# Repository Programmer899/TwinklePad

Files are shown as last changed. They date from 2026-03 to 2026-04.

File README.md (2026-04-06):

# Twinklepad

This is a small multi task keyboard with 3 custom modes, featuring a TRRS port for double connection, 2 encoders using GPIO and a display for displaying different contents.

Note that the parts that is not a part of the HackPad (https://blueprint.hackclub.com/home) guide will be bought or funded yourself.

---

## Features
1 pcs of 3 step toggle for switching mode
4x4 matrix of key switches
2 pcs of encoders for example slider values such as volume
1 ssd1306 128x32 display for displaying different types of content
1 TRRS port for dual connected modules (could be used for a split keyboard as an example)

---

## Modes

The Twinklepad has 3 modes by default
- Music mode (to the left) - when you press a key it plays a note
- Normal mode (in the middle) - when you press a key it forwards that to the pc as a keycode input
- Calc mode (on the right) - For future calculator mode, able to calculate differents formulas

The current mode for my trinklepad is shown on the display by default.
---

My firmware is written in c from the ground up and has some different features such as:
- Matrix scanning for key inputs
- Encoder control (default: only left is connected to "pitch")
- Display - only capable of displaying mode by default

---

## Hardware

- Raspberry Pi Pico 2 W
- 4x4 MX-style switches  
- 2 pcs Rotary encoders (with push buttons)
- SK6812-MINI-E LEDs 
- SSD1306 128x32 OLED
- Piezo buzzer 4.5 khz
- 3-position mode switch (ON-OFF-ON)

---

## Preview

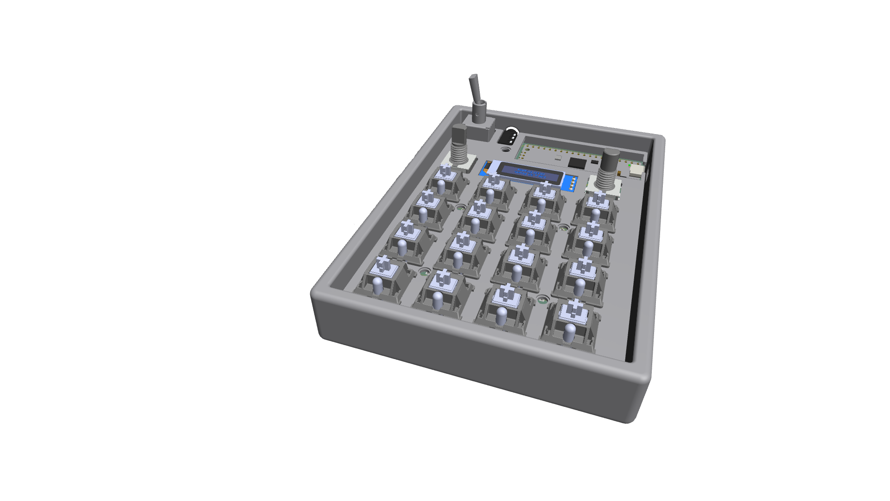
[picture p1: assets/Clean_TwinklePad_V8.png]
Twinklepad Preview


---

## Getting Started

Clean software:
1. Build with Pico SDK (CMake + Ninja)
2. Flash the `.uf2` file to the Pico
3. Connect via USB and start using HackPad

Use mine?
Just flash the .uf2 file in the fully assembled/production folder.

---

## Notes

This is one of my first times doing something like this.

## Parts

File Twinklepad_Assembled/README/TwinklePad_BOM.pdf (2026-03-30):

# Twinkle Pad BOM

MX Cherry switches for rgb: Cherry MX Red RGB (https://www.keychron.com/products/cherry-switch-set?variant=39317191196761) 16 pcs (4x4)

Raspberry Pico 2 W: Raspberry-pi-pico-2w (https://www.electrokit.com/raspberry-pi-pico-2w) 1 pcs

Buzzer: piezo-transducer-4.5khz (https://www.electrokit.com/piezo-transducer-4.5khz) 1 pcs

Sparkfun TRRS: PRT-12639_SparkFun (https://componentsearchengine.com/part-view/PRT-12639/SparkFun) 1 pcs

RGB SK6812MINI-E: SK6812MINI-E_REV02 (https://cdn-shop.adafruit.com/product-files/4960/4960_SK6812MINI-E_REV02_EN.pdf) 16 pcs

Rotary Encoders: tech.alpsalpine.com - ec11e (https://tech.alpsalpine.com/e/products/category/encorders/sub/01/series/ec11e/) 2 pcs

Display SSD1306 0.91: www.az-delivery.de - SSD1306 0.91 i2c-oled-display (https://www.az-delivery.de/en/products/0-91-zoll-i2c-oled-display) 1 pcs

3 Step switch 7205P3Y9CQE: www.mouser.se - 7205P3Y9CQE (https://www.mouser.se/ProductDetail/CK/7205P3Y9CQE?qs=ZI7IIxmAbBLtiAhiSZhUWA%3D%3D) 1 pcs

### Guides:

Buzzer Guide: pico-2w-kit/en/latest/pyproject/py_pa_buz (https://docs.sunfounder.com/projects/pico-2w-kit/en/latest/pyproject/py_pa_buz.html)

Twinkle Pad BOM | 1

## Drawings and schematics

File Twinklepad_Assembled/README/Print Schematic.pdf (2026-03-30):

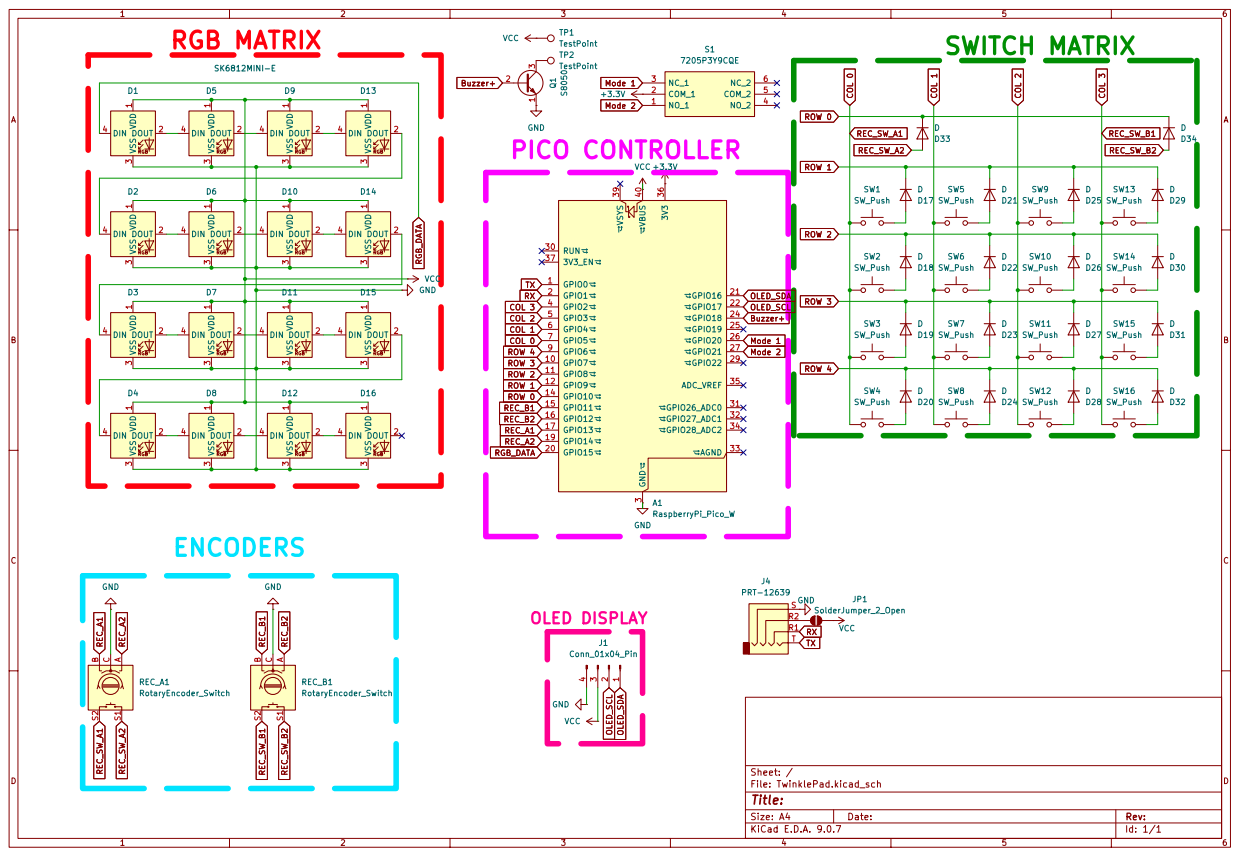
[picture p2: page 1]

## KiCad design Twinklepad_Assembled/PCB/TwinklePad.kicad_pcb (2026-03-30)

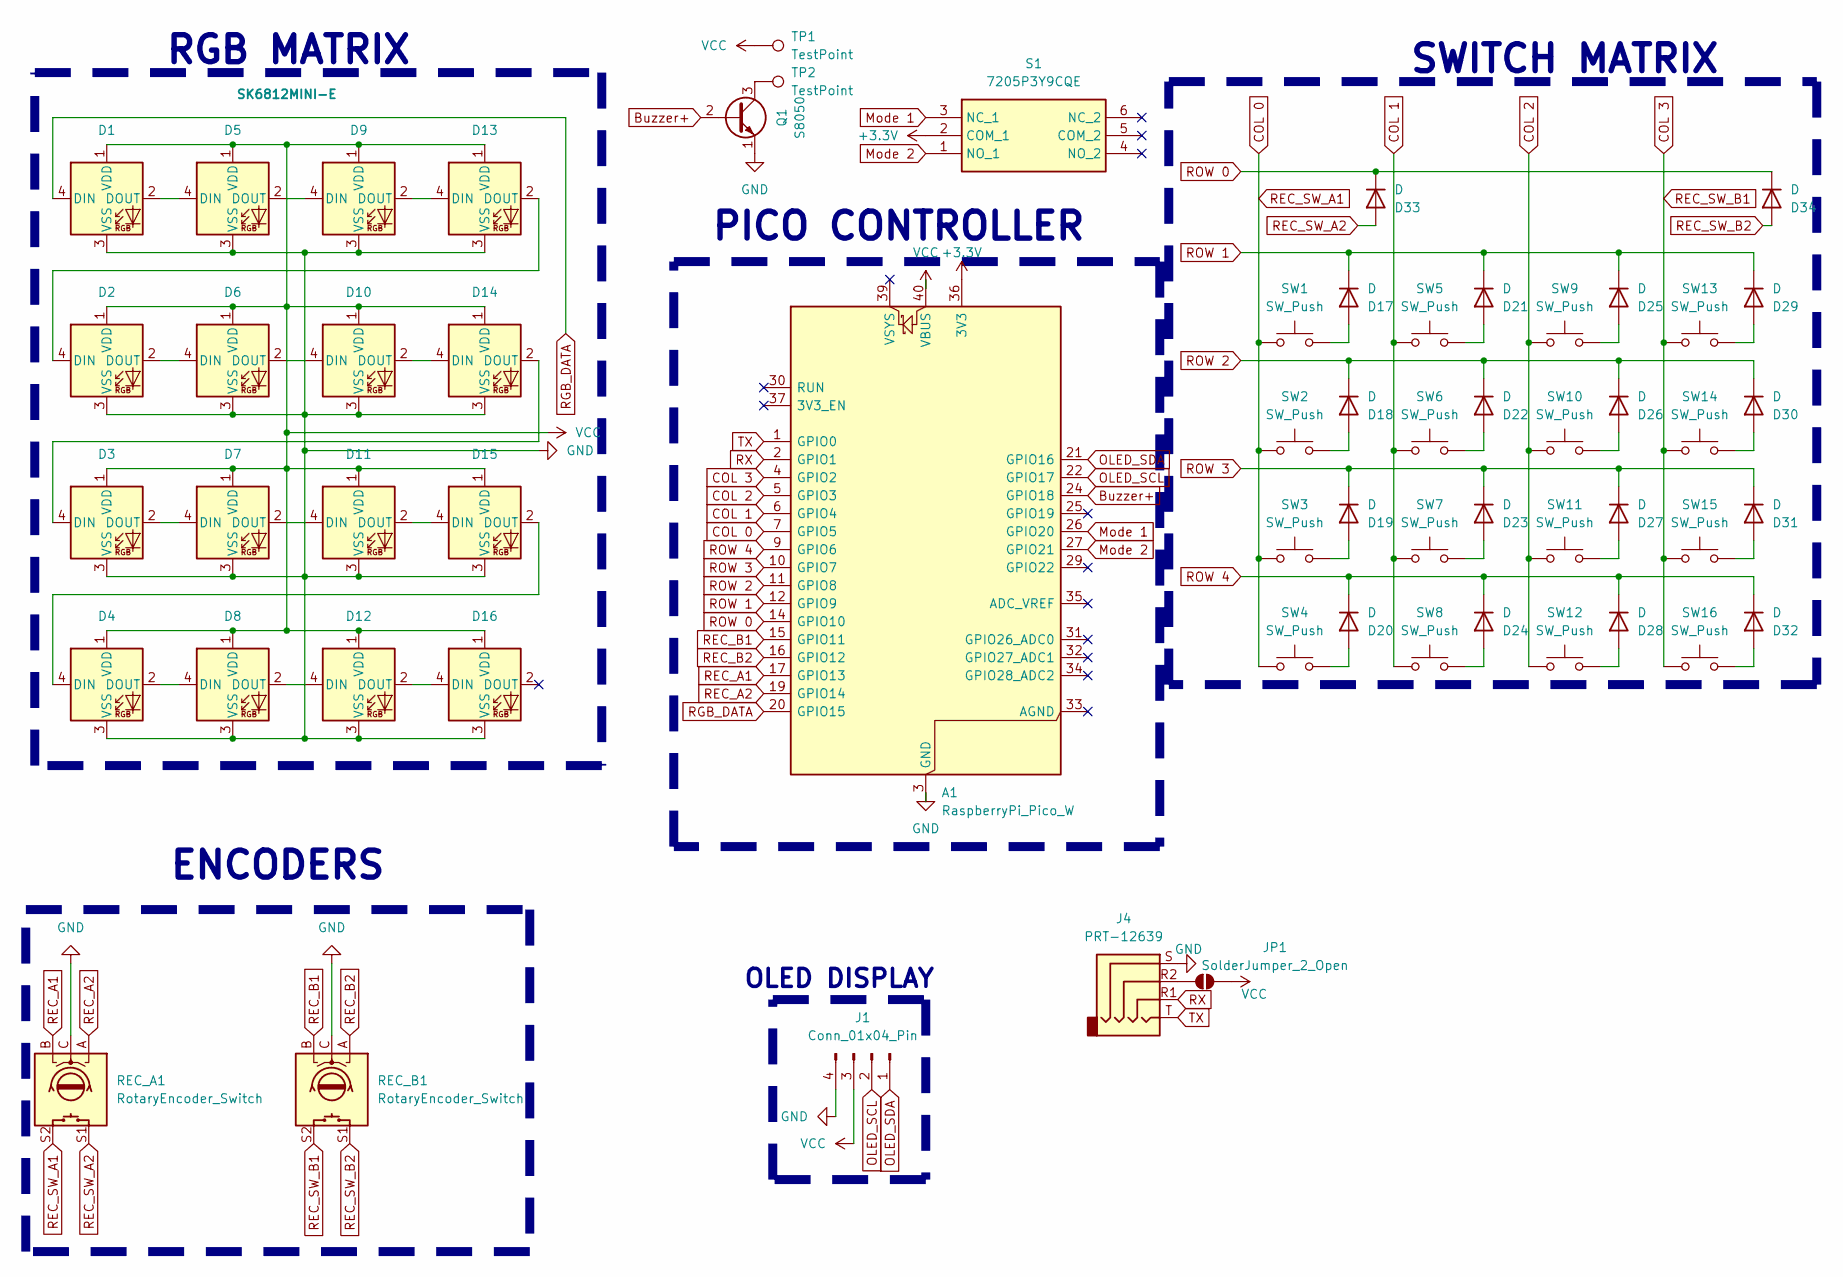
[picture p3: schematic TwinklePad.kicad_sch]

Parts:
A1: RaspberryPi_Pico_W; RaspberryPi_Pico_Common_Unspecified
D1, D2, D3, D4, D5, D6, D7, D8, D9, D10, D11, D12, D13, D14, D15, D16: SK6812MINI-E; SK6812MINI-E_fixed
D17, D18, D19, D20, D21, D22, D23, D24, D25, D26, D27, D28, D29, D30, D31, D32, D33, D34: D; D_DO-35_SOD27_P7.62mm_Horizontal
J1: Conn_01x04_Pin; SSD1306-0.91-OLED-4pin-128x32
J4: PRT-12639; PRT12639; Manufacturer_Part_Number PRT-12639; Mouser Part Number 474-PRT-12639
JP1: SolderJumper_2_Open; SolderJumper-2_P1.3mm_Open_RoundedPad1.0x1.5mm
Q1: S8050; TO-92_Inline_Horizontal1
REC_A1: RotaryEncoder_Switch; RotaryEncoder_Alps_EC11E-Switch_Vertical_H20mm
REC_B1: RotaryEncoder_Switch; RotaryEncoder_Alps_EC11E-Switch_Vertical_H20mm
S1: 7205P3Y9CQE; Manufacturer_Part_Number 7205P3Y9CQE; Mouser Part Number 611-7205P3Y9CQE
SW1, SW2, SW3, SW4, SW5, SW6, SW7, SW8, SW9, SW10, SW11, SW12, SW13, SW14, SW15, SW16: SW_Push; MX-Hotswap-1U
TP1, TP2: TestPoint; TestPoint_Plated_Hole_D2.0mm

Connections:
+3.3V: A1.36 (3V3), S1.2 (COM_1)
Buzzer+: A1.24 (GPIO18), Q1.2 (B)
COL 0: A1.7 (GPIO5), REC_A1.S2, SW1.1, SW2.1, SW3.1, SW4.1
COL 1: A1.6 (GPIO4), SW5.1, SW6.1, SW7.1, SW8.1
COL 2: A1.5 (GPIO3), SW9.1, SW10.1, SW11.1, SW12.1
COL 3: A1.4 (GPIO2), REC_B1.S2, SW13.1, SW14.1, SW15.1, SW16.1
GND: A1.3 (GND), A1.8 (GND), A1.13 (GND), A1.18 (GND), A1.23 (GND), A1.28 (GND), A1.38 (GND), D1.3 (VSS), D2.3 (VSS), D3.3 (VSS), D4.3 (VSS), D5.3 (VSS), D6.3 (VSS), D7.3 (VSS), D8.3 (VSS), D9.3 (VSS), D10.3 (VSS), D11.3 (VSS), D12.3 (VSS), D13.3 (VSS), D14.3 (VSS), D15.3 (VSS), D16.3 (VSS), J1.4, J4.S, Q1.1 (E), REC_A1.C, REC_B1.C
Mode 1: A1.26 (GPIO20), S1.3 (NC_1)
Mode 2: A1.27 (GPIO21), S1.1 (NO_1)
unnamed: D1.2 (DOUT), D5.4 (DIN)
unnamed: D2.2 (DOUT), D6.4 (DIN)
unnamed: D3.2 (DOUT), D7.4 (DIN)
unnamed: D4.2 (DOUT), D8.4 (DIN)
unnamed: D5.2 (DOUT), D9.4 (DIN)
unnamed: D6.2 (DOUT), D10.4 (DIN)
unnamed: D10.2 (DOUT), D14.4 (DIN)
unnamed: D7.2 (DOUT), D11.4 (DIN)
unnamed: D11.2 (DOUT), D15.4 (DIN)
unnamed: D8.2 (DOUT), D12.4 (DIN)
unnamed: D12.2 (DOUT), D16.4 (DIN)
unnamed: D9.2 (DOUT), D13.4 (DIN)
unnamed: D2.4 (DIN), D13.2 (DOUT)
unnamed: D3.4 (DIN), D14.2 (DOUT)
unnamed: D4.4 (DIN), D15.2 (DOUT)
unnamed: D17.2 (A), SW1.2
unnamed: D18.2 (A), SW2.2
unnamed: D19.2 (A), SW3.2
unnamed: D20.2 (A), SW4.2
unnamed: D21.2 (A), SW5.2
unnamed: D22.2 (A), SW6.2
unnamed: D23.2 (A), SW7.2
unnamed: D24.2 (A), SW8.2
unnamed: D25.2 (A), SW9.2
unnamed: D26.2 (A), SW10.2
unnamed: D27.2 (A), SW11.2
unnamed: D28.2 (A), SW12.2
unnamed: D29.2 (A), SW13.2
unnamed: D30.2 (A), SW14.2
unnamed: D31.2 (A), SW15.2
unnamed: D32.2 (A), SW16.2
unnamed: J4.R2, JP1.1 (A)
unnamed 41: Q1.3 (C), TP2.1; also elsewhere on the board
OLED_SCL: A1.22 (GPIO17), J1.2
OLED_SDA: A1.21 (GPIO16), J1.1
REC_A1: A1.17 (GPIO13), REC_A1.B
REC_A2: A1.19 (GPIO14), REC_A1.A
REC_B1: A1.15 (GPIO11), REC_B1.B
REC_B2: A1.16 (GPIO12), REC_B1.A
REC_SW_A2: D33.2 (A), REC_A1.S1
REC_SW_B2: D34.2 (A), REC_B1.S1
RGB_DATA: A1.20 (GPIO15), D1.4 (DIN)
ROW 0: A1.14 (GPIO10), D33.1 (K), D34.1 (K)
ROW 1: A1.12 (GPIO9), D17.1 (K), D21.1 (K), D25.1 (K), D29.1 (K)
ROW 2: A1.11 (GPIO8), D18.1 (K), D22.1 (K), D26.1 (K), D30.1 (K)
ROW 3: A1.10 (GPIO7), D19.1 (K), D23.1 (K), D27.1 (K), D31.1 (K)
ROW 4: A1.9 (GPIO6), D20.1 (K), D24.1 (K), D28.1 (K), D32.1 (K)
RX: A1.2 (GPIO1), J4.R1
TX: A1.1 (GPIO0), J4.T
VCC: A1.40 (VBUS), D1.1 (VDD), D2.1 (VDD), D3.1 (VDD), D4.1 (VDD), D5.1 (VDD), D6.1 (VDD), D7.1 (VDD), D8.1 (VDD), D9.1 (VDD), D10.1 (VDD), D11.1 (VDD), D12.1 (VDD), D13.1 (VDD), D14.1 (VDD), D15.1 (VDD), D16.1 (VDD), J1.3, JP1.2 (B), TP1.1; also elsewhere on the board

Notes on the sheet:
RGB MATRIX
SWITCH MATRIX
PICO CONTROLLER
ENCODERS
OLED DISPLAY

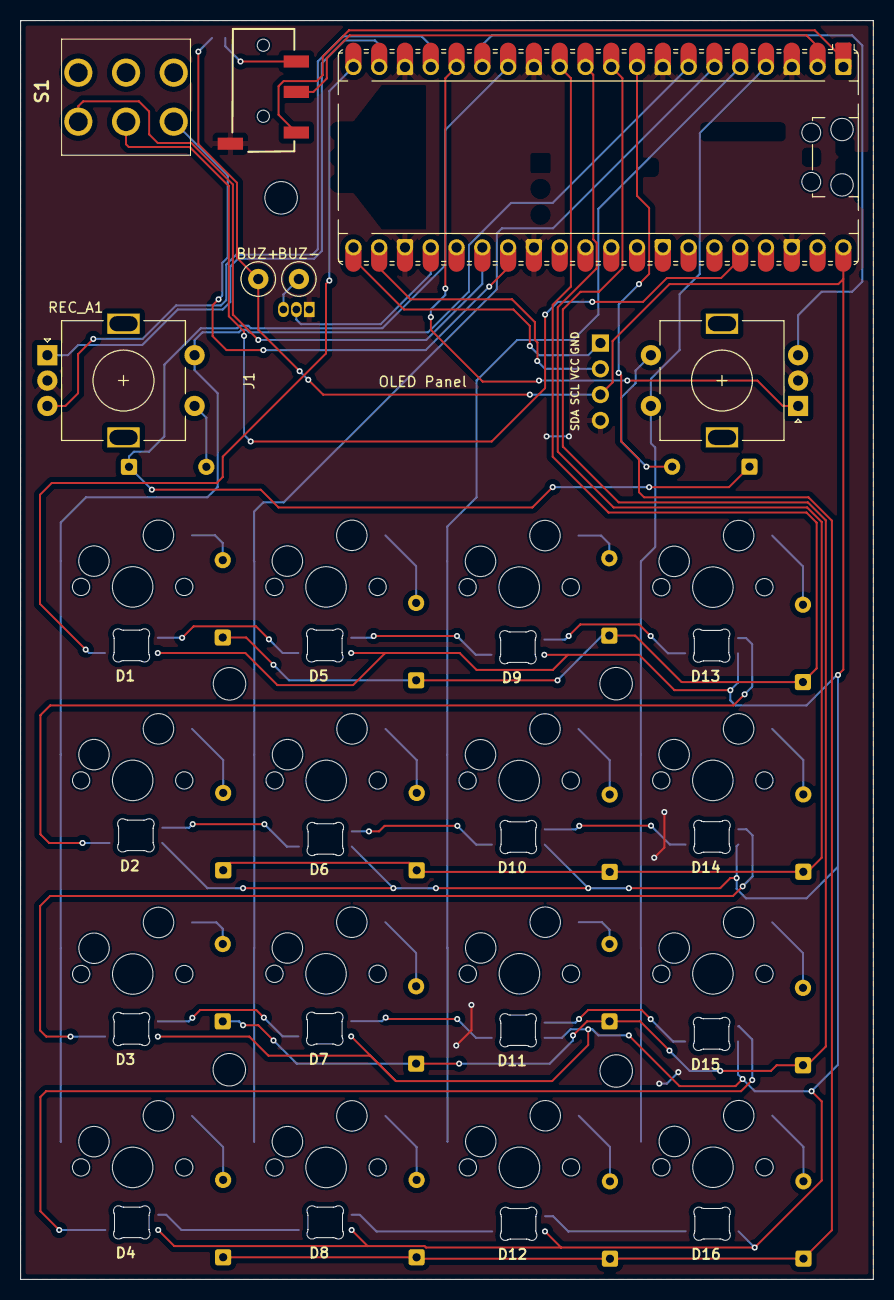
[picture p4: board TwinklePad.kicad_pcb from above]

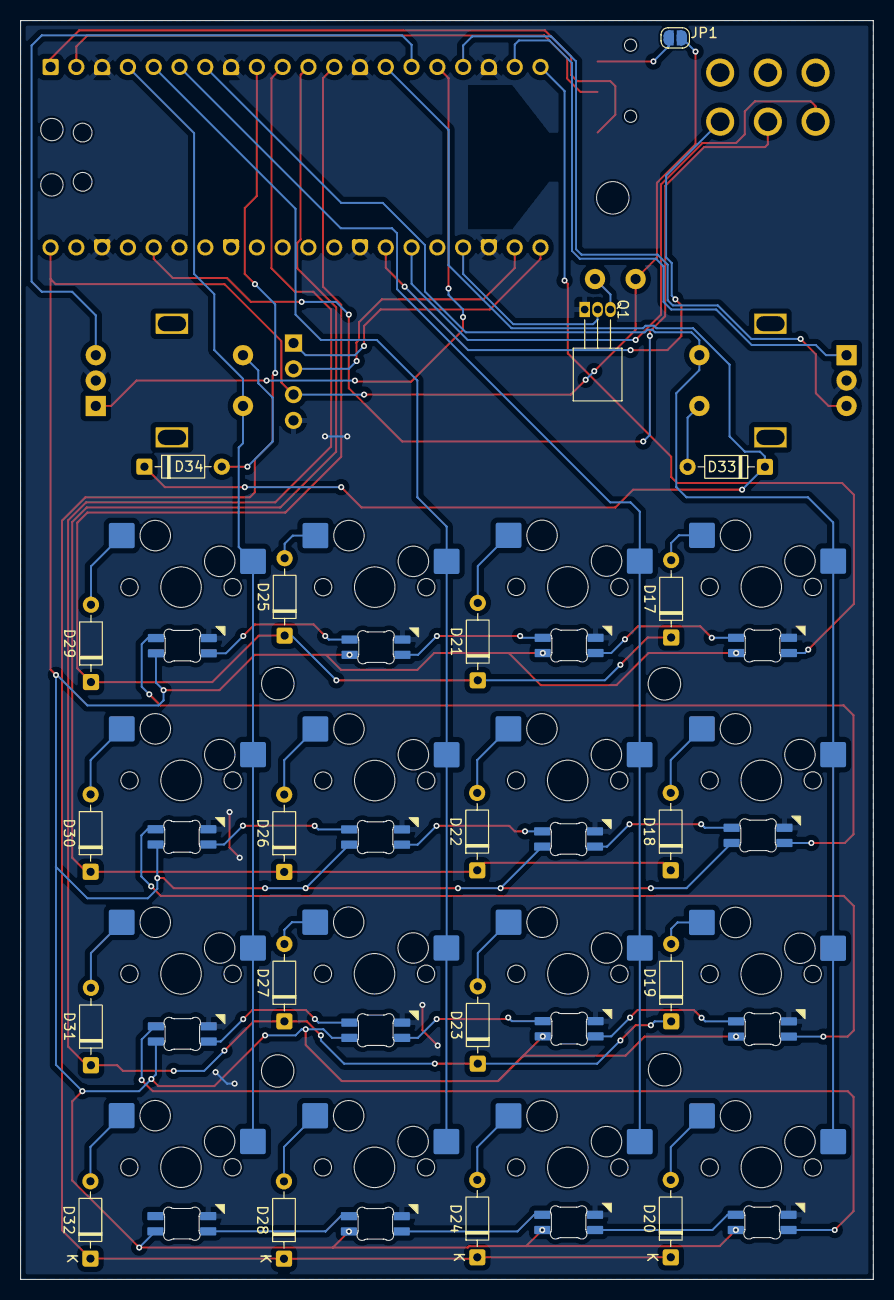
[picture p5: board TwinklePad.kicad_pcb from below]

Board: 2 copper layers, 84.0 x 124.0 mm, 60 parts (36 on the bottom side), 59 nets.

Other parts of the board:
BUZ+: TestPoint; TestPoint_Plated_Hole_D2.0mm
BUZ-: TestPoint; TestPoint_Plated_Hole_D2.0mm

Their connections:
unnamed 41: BUZ-.1; also elsewhere on the board
VCC: BUZ+.1; also elsewhere on the board

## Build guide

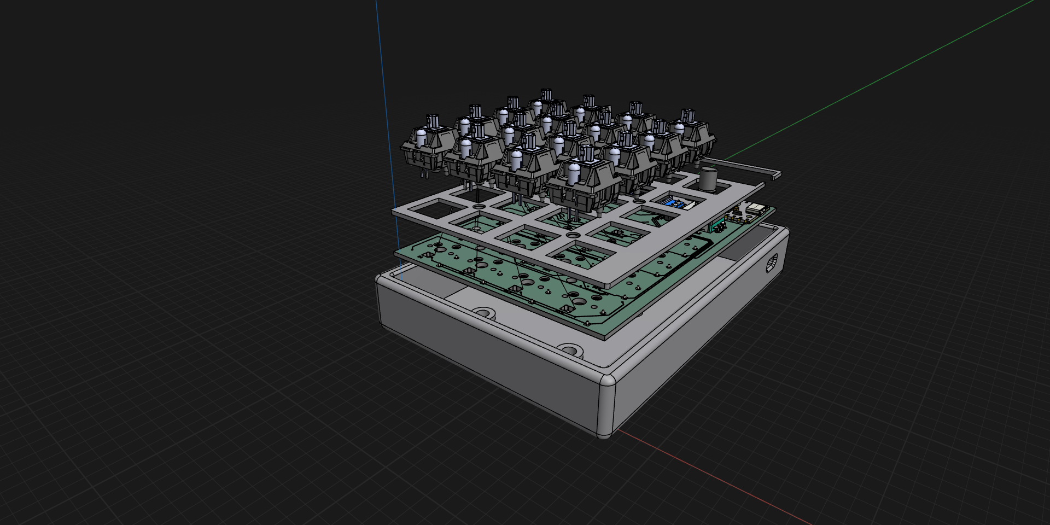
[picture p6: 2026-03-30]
Twinklepad_Assembled/README/TwinklePad_assemble_guide.png

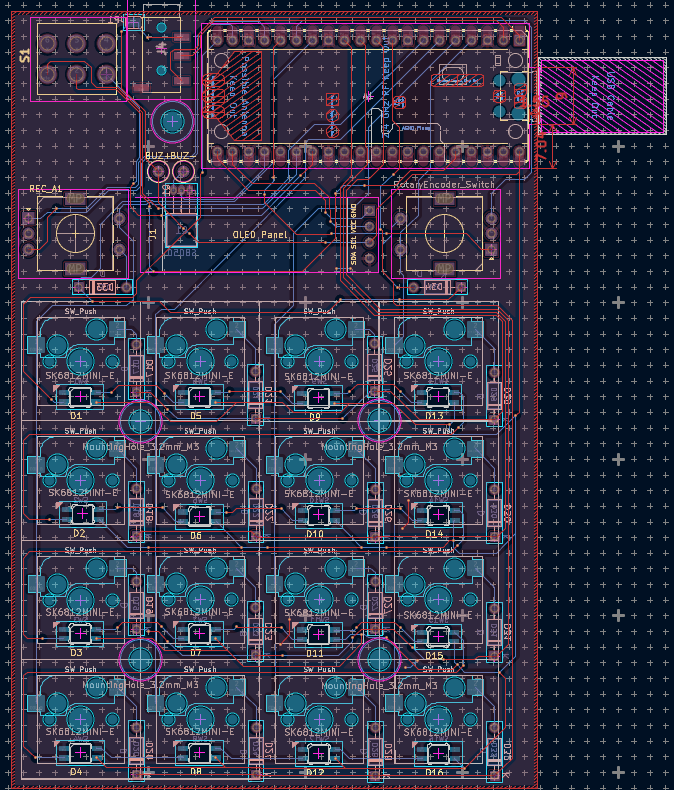
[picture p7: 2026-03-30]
Twinklepad_Assembled/README/TwinklePad_PCB.png

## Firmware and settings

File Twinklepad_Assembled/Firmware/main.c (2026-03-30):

#include <stdio.h>
#include "pico/stdlib.h"

#include "matrix.h"
#include "usb_hid.h"
#include "modes.h"
#include "rgb.h"
#include "buzzer.h"
#include "display.h"
#include "encoder.h"

Mode current_mode = MODE_NORMAL;
uint8_t lastMode;

Encoder encLeft;
Encoder encRight;

int main() {
  stdio_init_all();

  matrix_init();
  usb_hid_init();
  modes_init();
  rgb_init();
  buzzer_init();
  display_init();

  encoder_init(&encLeft, 13, 14);
  encoder_init(&encRight, 11, 12);

  uint8_t mode = modes_get();
  rgb_update(mode);
  display_update(mode);

  while (true) {
    //tud_task();

    matrix_scan();

    uint8_t mode = modes_get();

    encoder_update(&encLeft);
    encoder_update(&encRight);

    if (encLeft.updated) {
      printf("Left encoder: %d\n", encLeft.value);
      encLeft.updated = 0;
    }

    if (encRight.updated) {
      printf("Right encoder: %d\n", encRight.value);
      encRight.updated = 0;
    }

    // Only execute if switched mode
    if (lastMode != mode) {
      lastMode = mode;
      rgb_update(mode);
      display_update(mode);
      buzzer_stop();
    }

    if (mode == MODE_MUSIC) {
      int note = matrix_get_note();

      if (note > 0) {
        buzzer_play_freq(note * ((float)encLeft.value / (float)100));
      } else {
        buzzer_stop();
      }
    } else {
      uint8_t keys[6];
      matrix_get_keys(keys, mode);
      usb_hid_send(keys);
    }
    // sleep_ms(1);
    sleep_us(500);
  }
}

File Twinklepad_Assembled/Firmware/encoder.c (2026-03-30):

#include "encoder.h"
#include "pico/stdlib.h"

void encoder_init(Encoder *enc, uint8_t pinA, uint8_t pinB) {
  enc->pinA = pinA;
  enc->pinB = pinB;

  gpio_init(pinA);
  gpio_set_dir(pinA, GPIO_IN);
  gpio_pull_up(pinA);

  gpio_init(pinB);
  gpio_set_dir(pinB, GPIO_IN);
  gpio_pull_up(pinB);

  enc->lastA = gpio_get(pinA);
  enc->value = 0;
  enc->updated = 0;
}

void encoder_update(Encoder *enc) {
  uint8_t A = gpio_get(enc->pinA);
  uint8_t B = gpio_get(enc->pinB);

  // Only trigger on rising edge
  if (A != enc->lastA && A == 1) {
    enc->updated++;

    if (B != A) {
      enc->value--;   // counter-clockwise
    } else {
      enc->value++;   // clockwise
    }
  }

  enc->lastA = A;
}

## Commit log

2026-02-18 Init commit
    [TwinklePad.kicad_pcb, TwinklePad.kicad_sch]
2026-02-18 Made a complete schematic (maybe)
    [TwinklePad.kicad_pcb, TwinklePad.kicad_sch]
2026-03-04 Currently moving keys to layout
    [TwinklePad.kicad_pcb, TwinklePad.kicad_sch]
2026-03-07 Finished current version of the Twinklepad
    [TwinklePad.kicad_pcb]
2026-03-18 Finished PCB
    [TwinklePad.kicad_pcb, TwinklePad.kicad_sch]
2026-03-21 Updated PCB with new models and schematics
    [TwinklePad.kicad_pcb, TwinklePad.kicad_sch]
2026-03-25 Finished pcb, schematic and positioning - more or less
    [TwinklePad.kicad_pcb, TwinklePad.kicad_sch]
2026-03-28 Did some minor changes
    [TwinklePad.kicad_pcb]
2026-03-30 Ready for production if wanted
    [TwinklePad.kicad_pcb, TwinklePad.kicad_sch]
